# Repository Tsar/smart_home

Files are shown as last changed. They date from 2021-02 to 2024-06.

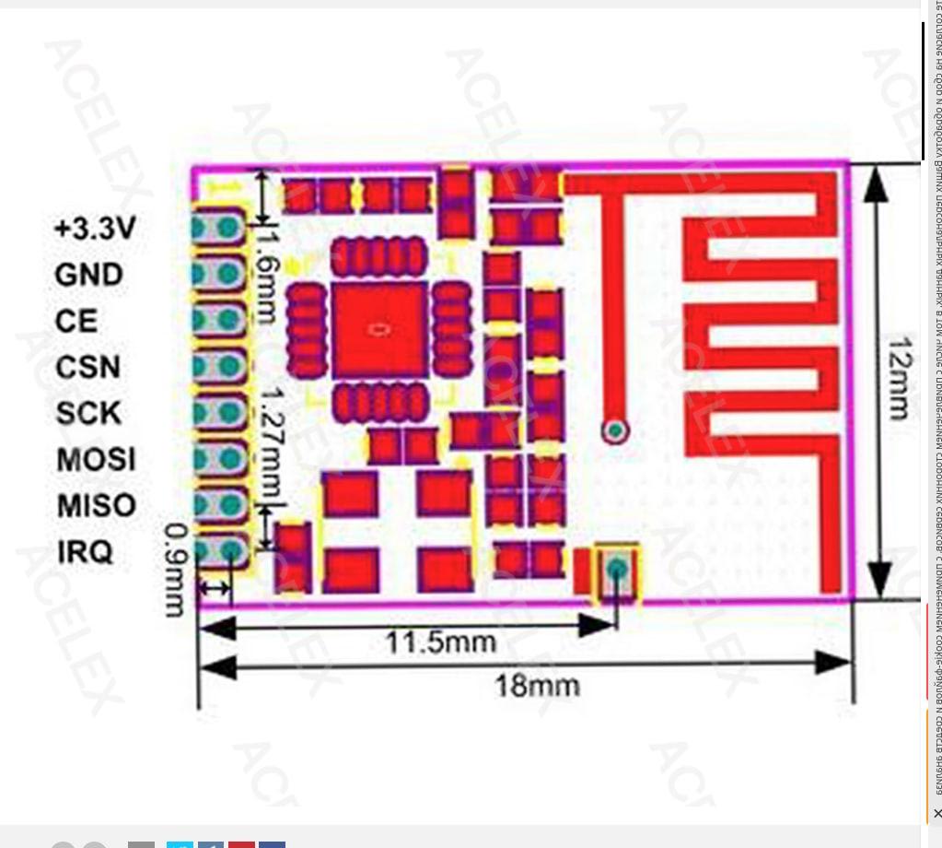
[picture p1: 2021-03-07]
nRF24L01_small_pinout.jpg

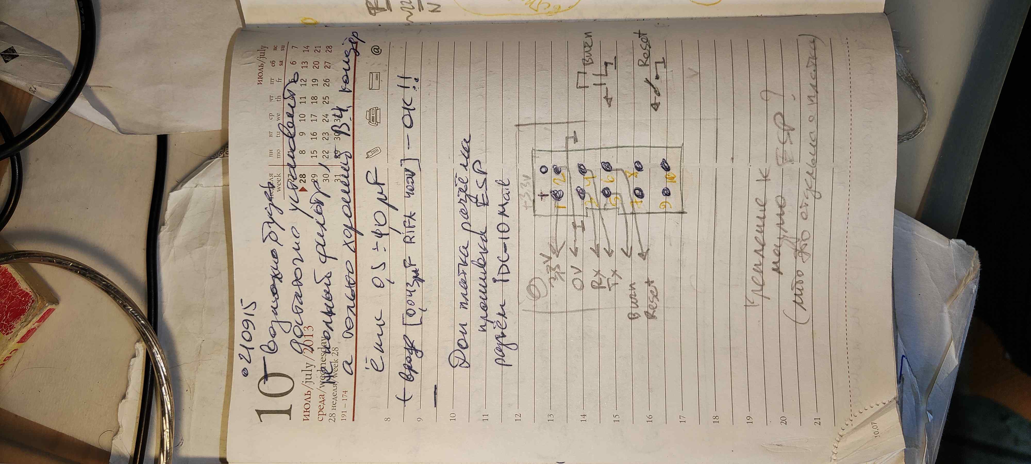
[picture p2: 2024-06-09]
Sprint_Layout_and_other_engineering_stuff/Smart_Home_Foto_Screenshots_Specs/КОнденс фильтра 43нФ 400В Rifa.jpg

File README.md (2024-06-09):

# Smart Home

## Key features

* Smooth light adjustment.
* Turning outlets on/off.
* Control via an Android app from anywhere in the world (with an external IP).
* Voice control via Yandex Alice or a smart speaker with Alice.

## Main project contents by folders

* **App** - Android application.
* **ESP8266_Firmware** - firmware for ESP8266.
* **Sprint_Layout_and_other_engineering_stuff** - contains schematics and other hardware information.
* **Voice_Integration** - script for processing requests from Alice and redirecting them to Smart Home devices.

## Successful usage

The project has been tested over a long period in two apartments. It is still in use in one of them to this day.

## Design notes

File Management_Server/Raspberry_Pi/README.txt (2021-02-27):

Actions to prepare and launch Smart Home Server:

1. sudo apt install make g++ git

2. ./install.sh

3. Choose to install only "RF24 core library"

Next stage is installing RF24 for Python (full doc here: https://nrf24.github.io/RF24/Python.html):

4. sudo apt install python3-dev libboost-python-dev python3-setuptools python3-rpi.gpio

5. sudo ln -s /usr/lib/arm-linux-gnueabihf/libboost_python38.so.1.71.0 /usr/lib/arm-linux-gnueabihf/libboost_python3.so

6. cd rf24libs/RF24/pyRF24/

7. python3 setup.py build

8. sudo python3 setup.py install

9. Change dir to script location

10. Create file "smart_home_password.txt" with password for HTTP access

11. sudo ./smart_home_server.py

Tsar. 27.02.2021

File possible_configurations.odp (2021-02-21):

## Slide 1

HTTP via Internet

Configuration 1

Android App

Ethernet

Raspberry Pi
Management Server

NRF

NRF

STM32
GPIO Switcher

NRF

STM32
GPIO Switcher

NRF

STM32
GPIO Switcher

…………………

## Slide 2

Bluetooth

Configuration 2

Android App

Bluetooth-USART

STM32
Management Server

NRF

NRF

STM32
GPIO Switcher

NRF

STM32
GPIO Switcher

NRF

STM32
GPIO Switcher

…………………

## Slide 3

HTTP via Internet

Configuration 3

Android App

Computer

USB-USART

STM32
Management Server

NRF

NRF

STM32
GPIO Switcher

NRF

STM32
GPIO Switcher

NRF

STM32
GPIO Switcher

…………………

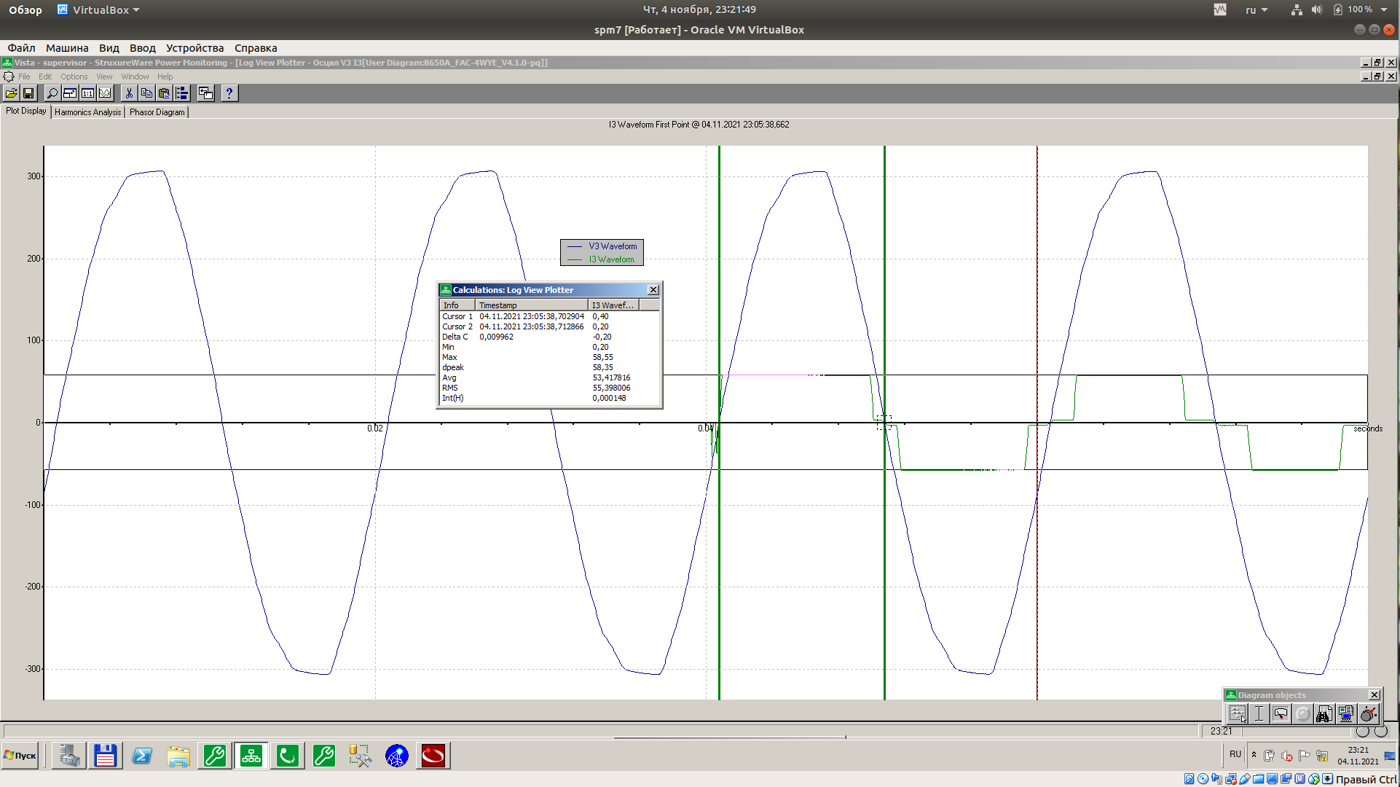
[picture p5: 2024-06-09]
Sprint_Layout_and_other_engineering_stuff/Smart_Home_Foto_Screenshots_Specs/Пик ток 58мА димм лампа Навиг7 W.png

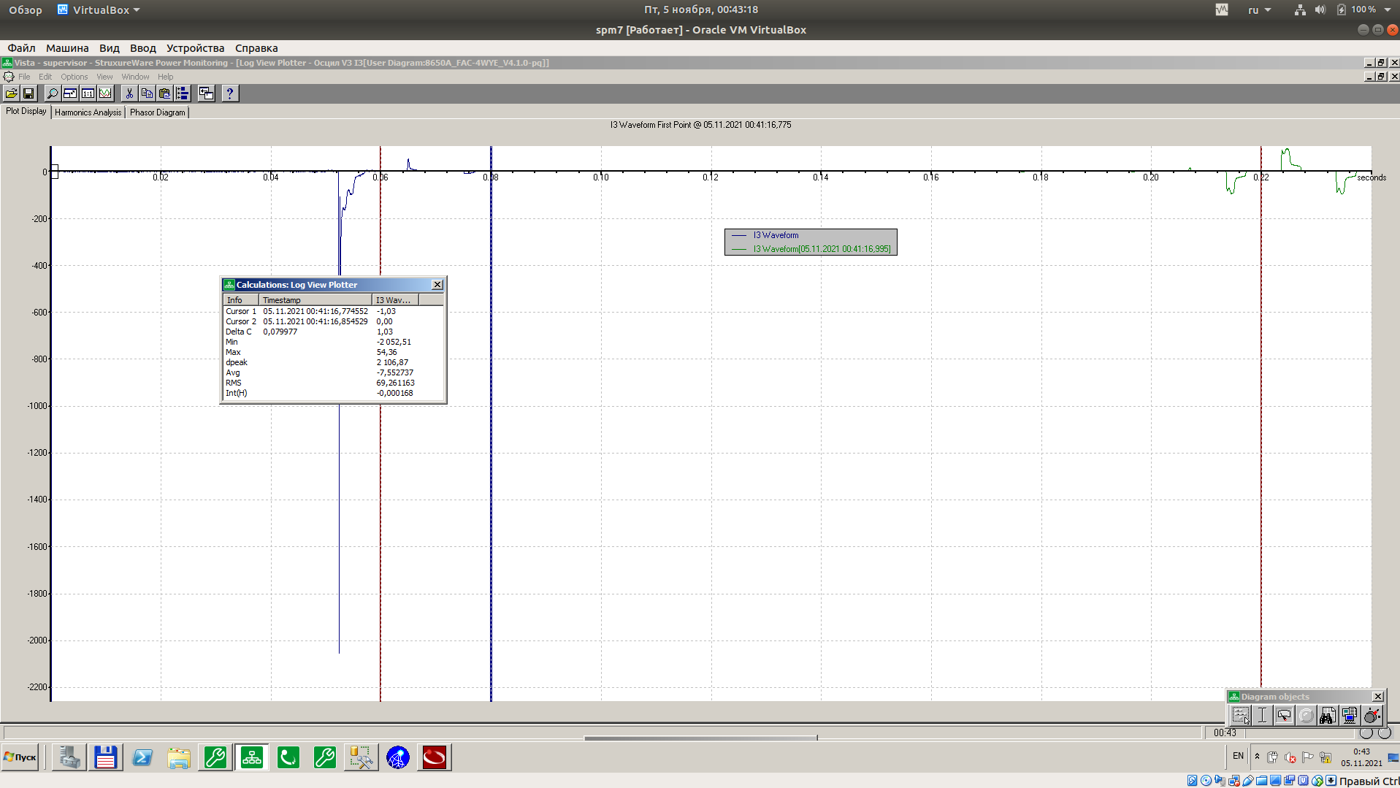
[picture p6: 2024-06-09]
Sprint_Layout_and_other_engineering_stuff/Smart_Home_Foto_Screenshots_Specs/Пик ток 2 А Не димм лампа Volpe 7 W.png

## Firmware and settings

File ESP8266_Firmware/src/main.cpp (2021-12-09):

#include <ESP8266WiFi.h>
#include <ESP8266WiFiGratuitous.h>
#include <ESP8266WebServer.h>
#include <ESP8266HTTPUpdateServer.h>
#include <WiFiUdp.h>
#include <lwip/igmp.h>

#include "configuration.hpp"

#define SIGN(val) (val > 0 ? 1 : (val < 0 ? -1 : 0))
#define MIN(val1, val2) ((val1) < (val2) ? (val1) : (val2))

#define HTTP_SERVER_PORT 80

#define FIRMWARE_VERSION 6  // used as uint16_t, increase when making new firmware version

#define UPDATER_USERNAME "admin"

#define DIMMER_PREFIX   "dim"
#define SWITCHER_PREFIX "sw"

#define INPUT_PIN 14  // for 50 Hz meander

volatile uint32_t inputFallTimeMs = 0;
volatile uint32_t inputFallsCount = 0;

const uint8_t DIMMER_PINS[DIMMERS_COUNT] = {4, 5, 12};
const uint8_t SWITCHER_PINS[SWITCHERS_COUNT] = {13, 15};

#define DIMMER_MAX_VALUE 1000

volatile int32_t dimmerValues[DIMMERS_COUNT] = {};  // 0 - диммер выключен, 1 - минимальная яркость, 1000 - максимальная яркость
volatile int32_t targetDimmerValues[DIMMERS_COUNT] = {};

const volatile smart_home::DimmerSettings* dimmersSettings;

struct Event {
  uint32_t ticks;  // число тиков таймера, начиная от input fall
  uint8_t pin;
  uint8_t value;
};

#define DIMMER_EVENTS_COUNT 4  // число событий для одного выхода диммера

// настройки событий
const uint32_t EVENT_ADDITIONAL_OFFSETS[DIMMER_EVENTS_COUNT] = {0, 500, 50000, 50500};
const uint8_t  EVENT_VALUES            [DIMMER_EVENTS_COUNT] = {HIGH, LOW, HIGH, LOW};

#define MAX_EVENTS_COUNT (DIMMERS_COUNT * DIMMER_EVENTS_COUNT)

volatile Event eventsQueue[MAX_EVENTS_COUNT];
volatile uint8_t eventsQueueSize = 0;
volatile uint8_t nextEventId = 0;

ESP8266WebServer server(HTTP_SERVER_PORT);
ESP8266HTTPUpdateServer updateServer;  // for updating firmware over wi-fi
smart_home::Configuration homeCfg;

std::vector<char> binInfoStorage;

enum class WiFiSetupState {
  NONE,
  IN_PROGRESS,
  FAIL,
  SUCCESS
};

WiFiSetupState wifiSetupState = WiFiSetupState::NONE;
int8_t wifiConnectResult = 0;
bool isAccessPointEnabled = false;

// Для обнаружения
const String UDP_SCAN_REQUEST = "SMART_HOME_SCAN";  // should fit udpInputBuffer
const IPAddress UDP_MULTICAST_IP(227, 16, 119, 203);
#define UDP_MULTICAST_PORT 25061
#define UDP_RESPONSE_PORT  25062

WiFiUDP udp;
char udpInputBuffer[32];
uint32_t udpScanCounter = 0;

#define REJOIN_MULTICAST_GROUP_INTERVAL 120000  // 2 minutes
Ticker rejoinMulticastGroupTicker;

// Кодовая последовательность продолжительности включений контроллера для сброса настроек wi-fi, допустимо отклонение на 20%
const std::vector<uint32_t> WIFI_RESET_SEQUENCE = {20000, 2000, 10000};
Ticker wifiResetSequenceDetectorTicker;

// Плавное изменение яркости
ICACHE_RAM_ATTR void smoothLightnessChange() {
  for (uint8_t i = 0; i < DIMMERS_COUNT; ++i) {
    const int32_t delta = targetDimmerValues[i] - dimmerValues[i];
    if (delta != 0) {
      const int32_t valueChangeStep = dimmersSettings[i].valueChangeStep;
      dimmerValues[i] += std::abs(delta) > valueChangeStep ? SIGN(delta) * valueChangeStep : delta;
    }
  }
}

#define COSINE_FORMULA  // если закомментировать, то будет линейная интерполяция

#ifdef COSINE_FORMULA
// Не удаётся использовать обычный cos, прошивка начинает крешиться (видимо, потому что он не в RAM)
// Источник этой реализации: https://stackoverflow.com/a/28050328
ICACHE_RAM_ATTR double fastCos(double x) {
    constexpr double tp = 1. / (2. * PI);
    x *= tp;
    x -= 0.25 + static_cast<int>(x + 0.25);  // using static_cast instead of floor, because in our case following is always true: x + 0.25 > 0
    x *= 16. * (std::abs(x) - 0.5);
    x += 0.225 * x * (std::abs(x) - 1.);
    return x;
}
#endif

// Переводит значение со слайдера в отступ импульса в микросекундах, см. dimmer_micros_adjustment.png
ICACHE_RAM_ATTR uint32_t dimmerValueToMicros(int32_t value, uint8_t dimmerId) {
  const int32_t minLM = dimmersSettings[dimmerId].minLightnessMicros;  // дефолт = 8300
  const int32_t maxLM = dimmersSettings[dimmerId].maxLightnessMicros;  // дефолт = 4000
#ifdef COSINE_FORMULA
  return fastCos(PI * (value - 1) / 2 / (DIMMER_MAX_VALUE - 1)) * (minLM - maxLM) + maxLM + 0.5;
#else
  return static_cast<double>(value - 1) * (maxLM - minLM) / (DIMMER_MAX_VALUE - 1) + minLM;
#endif
}

// Формируем новую очередь событий, начнутся со следующего input fall
ICACHE_RAM_ATTR void createEventsQueue() {
  uint8_t ev = 0;
  for (uint8_t i = 0; i < DIMMERS_COUNT; ++i) {
    if (dimmerValues[i] <= 0) {
      // для подстраховки: пин по идее и без этого должен стоять в LOW
      digitalWrite(DIMMER_PINS[i], LOW);
    } else {
      // добавляем 4 события для диммера в очередь
      const uint32_t offsetTicks = 5 * dimmerValueToMicros(dimmerValues[i], i);
      for (uint8_t j = 0; j < DIMMER_EVENTS_COUNT; ++j) {
        eventsQueue[ev].pin = DIMMER_PINS[i];
        eventsQueue[ev].ticks = offsetTicks + EVENT_ADDITIONAL_OFFSETS[j];
        eventsQueue[ev].value = EVENT_VALUES[j];
        ++ev;
      }
    }
  }
  eventsQueueSize = ev;

  // bubble sort is good enough for 12 or less elements
  for (uint8_t i = 0; i < eventsQueueSize - 1; ++i) {
    for (uint8_t j = 0; j < eventsQueueSize - i - 1; ++j) {
      if (eventsQueue[j].ticks > eventsQueue[j + 1].ticks) {
        std::swap(eventsQueue[j].ticks, eventsQueue[j + 1].ticks);
        std::swap(eventsQueue[j].pin, eventsQueue[j + 1].pin);
        std::swap(eventsQueue[j].value, eventsQueue[j + 1].value);
      }
    }
  }
}

ICACHE_RAM_ATTR void onInputFall() {
  // защита от многократных срабатываний на одном FALLING
  // и от срабатываний на RISING, которые тоже иногда случались
  const uint32_t now = millis();
  if (now - inputFallTimeMs < 15) return;
  inputFallTimeMs = now;
  ++inputFallsCount;

  nextEventId = 0;
  if (eventsQueueSize > 0) {
    timer1_write(eventsQueue[0].ticks);
  } else {
    smoothLightnessChange();
    createEventsQueue();
  }
}

ICACHE_RAM_ATTR void onTimerISR() {
  if (nextEventId >= eventsQueueSize) return;

  // выполнить event
  const auto& event = eventsQueue[nextEventId++];
  digitalWrite(event.pin, event.value);

  // выполнить все следующие event'ы с такой же меткой времени
  while (nextEventId < eventsQueueSize && eventsQueue[nextEventId].ticks == event.ticks) {
    const auto& nextEvent = eventsQueue[nextEventId];
    digitalWrite(nextEvent.pin, nextEvent.value);
    ++nextEventId;
  }

  if (nextEventId < eventsQueueSize) {
    const uint32_t ticksTillNextEvent = eventsQueue[nextEventId].ticks - event.ticks;  // в случае корректной работы всегда будет >= 5
    timer1_write(ticksTillNextEvent >= 5 ? ticksTillNextEvent : 5);                    // но подстрахуемся
  } else {
    // после выполнения всех event'ов
    smoothLightnessChange();
    createEventsQueue();
  }
}

void initCfgDimmerValuesAfterBoot() {
  const uint16_t dimmerValueAfterBoot = homeCfg.getDimmerValueAfterBoot();
  if (dimmerValueAfterBoot != 0xFFFF) {
    for (uint8_t i = 0; i < DIMMERS_COUNT; ++i) {
      homeCfg.setDimmerValue(i, MIN(dimmerValueAfterBoot, DIMMER_MAX_VALUE));
    }
  }
}

void fillDimmerValues() {
  for (uint8_t i = 0; i < DIMMERS_COUNT; ++i) {
    targetDimmerValues[i] = homeCfg.getDimmerValue(i);
  }
}

void initCfgSwitcherValuesAfterBoot() {
  const uint8_t switcherValueAfterBoot = homeCfg.getSwitcherValueAfterBoot();
  if (switcherValueAfterBoot != 0xFF) {
    for (uint8_t i = 0; i < SWITCHERS_COUNT; ++i) {
      homeCfg.setSwitcherValue(i, switcherValueAfterBoot > 0);
    }
  }
}

void applySwitcherValues() {
  for (uint8_t i = 0; i < SWITCHERS_COUNT; ++i) {
    digitalWrite(SWITCHER_PINS[i], homeCfg.getSwitcherValue(i) != homeCfg.isSwitcherInverted(i) ? HIGH : LOW);
  }
}

void fastBlinkForever() {
  while (true) {
    digitalWrite(LED_BUILTIN, LOW);
    delay(30);
    digitalWrite(LED_BUILTIN, HIGH);
    delay(30);
  }
}

// Same as WiFi.disconnect(true), but without touching config
void disconnectWiFi() {
    if (WiFi.getMode() & WIFI_STA) {
      wifi_station_disconnect();
    }
    WiFi.enableSTA(false);
}

void rejoinMulticastGroup() {
  const auto& ip = WiFi.localIP();
  Serial.printf("IGMP leave group %s\n", igmp_leavegroup(ip, UDP_MULTICAST_IP) == ERR_OK ? "OK" : "failed");
  Serial.printf("IGMP join group %s\n", igmp_joingroup(ip, UDP_MULTICAST_IP) == ERR_OK ? "OK" : "failed");
}

void enableAccessPoint() {
  if (isAccessPointEnabled) return;

  uint8_t mac[WL_MAC_ADDR_LENGTH];
  WiFi.macAddress(mac);
  char softAPName[32] = {};
  sprintf(softAPName, "SmartHomeDevice_%02X%02X%02X", mac[3], mac[4], mac[5]);

  Serial.printf("Enabling access point '%s' ... ", softAPName);
  const bool result = WiFi.softAP(softAPName, "setup12345");
  if (!result) {
    Serial.println("Failed");
    fastBlinkForever();
    return;
  }

  const String ip = WiFi.softAPIP().toString();
  Serial.printf("Access point enabled, IP: %s\n", ip.c_str());
  digitalWrite(LED_BUILTIN, LOW);
  isAccessPointEnabled = true;
}

bool connectToWiFi(const char* ssid, const char* passphrase, bool connectInfinitely) {
  digitalWrite(LED_BUILTIN, LOW);
  udp.stop();

  Serial.printf("Connecting to wi-fi: SSID '%s', passphrase '%s'\n", ssid, passphrase);
  WiFi.begin(ssid, passphrase);

  wifiConnectResult = WiFi.waitForConnectResult(30000);
  while (wifiConnectResult != WL_CONNECTED) {
    if (!connectInfinitely) {
      Serial.printf("Failed to connect, status: %d\n", wifiConnectResult);
      return false;
    }
    Serial.printf("Not yet connected, status: %d\n", wifiConnectResult);
    delay(1000);  // making delay for part of wait, because sometimes waitForConnectResult exits immediately
    wifiConnectResult = WiFi.waitForConnectResult(9000);
  }

  const auto& ip = WiFi.localIP();
  Serial.printf("Connected, IP: %s\n", ip.toString().c_str());
  digitalWrite(LED_BUILTIN, HIGH);

  // This should partly help for quick responses, details: https://github.com/esp8266/Arduino/issues/6886
  experimental::ESP8266WiFiGratuitous::stationKeepAliveSetIntervalMs();

  const bool listeningMulticast = udp.beginMulticast(ip, UDP_MULTICAST_IP, UDP_MULTICAST_PORT);
  if (listeningMulticast) {
    Serial.printf("Started listening UDP multicast on %s:%d\n", UDP_MULTICAST_IP.toString().c_str(), UDP_MULTICAST_PORT);
    rejoinMulticastGroupTicker.detach();
    rejoinMulticastGroupTicker.attach_ms_scheduled(REJOIN_MULTICAST_GROUP_INTERVAL, rejoinMulticastGroup);
  } else {
    Serial.println("Failed to start listening UDP multicast");
  }

  return true;
}

bool checkPassword() {
  if (server.hasHeader("Password") && server.header("Password") == homeCfg.getPassword()) {
    return true;
  }
  server.send(403, "text/plain", "Forbidden");
  Serial.printf("Sent 403 for %s\n", server.uri().c_str());
  return false;
}

void sendBadRequest() {
  server.send(400, "text/plain", "Bad Request");
  Serial.printf("Sent 400 for %s\n", server.uri().c_str());
}

// Create JSON (inefficient function, only for manual debugging)
String generateInfoJson(bool minimal) {
  String result = "{\n  \"mac\": \"" + WiFi.macAddress()
              + "\",\n  \"name\": \"" + homeCfg.getName()
              + "\",\n  \"firmware_version\": " + String(FIRMWARE_VERSION);
  if (!minimal) {
    result += ",\n  \"values\": {\n    \"";
    for (uint8_t i = 0; i < DIMMERS_COUNT; ++i) {
      result += DIMMER_PREFIX + String(i) + "\": " + String(homeCfg.getDimmerValue(i)) + ",\n    \"";
    }
    for (uint8_t i = 0; i < SWITCHERS_COUNT; ++i) {
      result += SWITCHER_PREFIX + String(i) + "\": " + (homeCfg.getSwitcherValue(i) ? "1" : "0") + (i + 1 == SWITCHERS_COUNT ? "" : ",\n    \"");
    }
    result += "\n  },\n  \"micros\": {\n    \"";
    for (uint8_t i = 0; i < DIMMERS_COUNT; ++i) {
      const uint16_t value = homeCfg.getDimmerValue(i);
      result += DIMMER_PREFIX + String(i) + "\": " + String(value > 0 ? dimmerValueToMicros(value, i) : -1) + (i + 1 == DIMMERS_COUNT ? "" : ",\n    \"");
    }
    result += "\n  },\n  \"dimmers_settings\": {\n    \"";
    for (uint8_t i = 0; i < DIMMERS_COUNT; ++i) {
      result += DIMMER_PREFIX + String(i) + "\": {\n      \"value_change_step\": " + String(dimmersSettings[i].valueChangeStep)
                                              + ",\n      \"min_lightness_micros\": " + String(dimmersSettings[i].minLightnessMicros)
                                              + ",\n      \"max_lightness_micros\": " + String(dimmersSettings[i].maxLightnessMicros)
                                              + "\n    }" + (i + 1 == DIMMERS_COUNT ? "" : ",\n    \"");
    }
    result += "\n  },\n  \"dimmer_value_after_boot\": " + String(homeCfg.getDimmerValueAfterBoot()) + ",\n  \"switchers_inverted\": {\n    \"";
    for (uint8_t i = 0; i < SWITCHERS_COUNT; ++i) {
      result += SWITCHER_PREFIX + String(i) + "\": " + (homeCfg.isSwitcherInverted(i) ? "1" : "0") + (i + 1 == SWITCHERS_COUNT ? "" : ",\n    \"");
    }
    result += "\n  },\n  \"switcher_value_after_boot\": " + String(homeCfg.getSwitcherValueAfterBoot()) + ",\n  \"additional_blob\": \"";
    const String& additionalBlob = homeCfg.getAdditionalBlob();
    for (unsigned int i = 0; i < additionalBlob.length(); ++i) {
      result += String(additionalBlob[i], 16) + (i + 1 == additionalBlob.length() ? "" : " ");
    }
    const auto currentUptime = millis();
    result += "\",\n  \"uptime_ms\": " + String(currentUptime)
            + ",\n  \"input_falls_count\": " + String(inputFallsCount)
            + ",\n  \"average_input_fall_interval_ms\": " + String(static_cast<double>(currentUptime) / inputFallsCount, 5);
  }
  result += "\n}\n";
  return result;
}

class UnalignedBinarySerializer {
public:
  UnalignedBinarySerializer(char* buffer) : buffer_(buffer), pos_(0) {}

  void writeWiFiMacAddress() {
    WiFi.macAddress(reinterpret_cast<uint8_t*>(buffer_ + pos_));
    pos_ += WL_MAC_ADDR_LENGTH;
  }

  void writeUInt8(uint8_t value) {
    buffer_[pos_++] = value;
  }

  void writeUInt16(uint16_t value) {
    memcpy(buffer_ + pos_, &value, 2);
    pos_ += 2;
  }

  void writeString(String value) {
    writeUInt16(value.length());
    memcpy(buffer_ + pos_, value.c_str(), value.length());
    pos_ += value.length();
  }

  size_t getWrittenSize() const {
    return pos_;
  }

private:
  char* buffer_;
  size_t pos_;
};

// Fill binInfoStorage
void generateInfoBinary(uint8_t version) {
  const bool v3 = version >= 3;  // request is for v3 or more
  const bool v4 = version >= 4;  // request is for v4 or more

  const String name = homeCfg.getName();
  const String additionalBlob = homeCfg.getAdditionalBlob();

  //                                                      Sizes of:
  const size_t sz = (v3 ? 2 : 0)                            // response format version (appeared from 3+)
                  + (v4 ? 2 : 0)                            // firmware version (appeared from 4+)
                  + WL_MAC_ADDR_LENGTH                      // MAC
                  + 2 + name.length()                       // name length and name
                  + 1                                       // input pin number
                  + 1 + DIMMERS_COUNT * 9 + (v3 ? 2 : 0)    // dimmers info
                  + 1 + SWITCHERS_COUNT * 3 + (v3 ? 1 : 0)  // switchers info
                  + 2 + additionalBlob.length();            // some App's GUI display settings
  binInfoStorage.resize(sz);

  UnalignedBinarySerializer serializer(binInfoStorage.data());
  if (v4) {
    serializer.writeUInt16(0x0004);
    serializer.writeUInt16(FIRMWARE_VERSION);
  } else if (v3) {
    serializer.writeUInt16(0x0003);
  }
  serializer.writeWiFiMacAddress();
  serializer.writeString(name);
  serializer.writeUInt8(INPUT_PIN);

  serializer.writeUInt8(DIMMERS_COUNT);
  for (uint8_t i = 0; i < DIMMERS_COUNT; ++i) {
    serializer.writeUInt8(DIMMER_PINS[i]);
    serializer.writeUInt16(homeCfg.getDimmerValue(i));
    serializer.writeUInt16(dimmersSettings[i].valueChangeStep);
    serializer.writeUInt16(dimmersSettings[i].minLightnessMicros);
    serializer.writeUInt16(dimmersSettings[i].maxLightnessMicros);
  }
  if (v3) {
    serializer.writeUInt16(homeCfg.getDimmerValueAfterBoot());
  }

  serializer.writeUInt8(SWITCHERS_COUNT);
  for (uint8_t i = 0; i < SWITCHERS_COUNT; ++i) {
    serializer.writeUInt8(SWITCHER_PINS[i]);
    serializer.writeUInt8(homeCfg.getSwitcherValue(i));
    serializer.writeUInt8(homeCfg.isSwitcherInverted(i));
  }
  if (v3) {
    serializer.writeUInt8(homeCfg.getSwitcherValueAfterBoot());
  }

  serializer.writeString(additionalBlob);

  if (serializer.getWrittenSize() != sz) {
    Serial.printf("WARNING: Serialized: %d, expected: %d\n", serializer.getWrittenSize(), sz);
  }
}

void handleGetInfo() {
  const auto tsStart = micros64();

  if (!checkPassword()) return;

  if (server.hasArg("binary")) {
    generateInfoBinary(server.hasArg("v") ? server.arg("v").toInt() : 1);
    server.send(200, "application/octet-stream", binInfoStorage.data(), binInfoStorage.size());
  } else {
    server.send(200, "application/json", generateInfoJson(server.hasArg("minimal")));
  }

  const auto tsEnd = micros64();
  Serial.printf("Handled %s, spent %.2lf ms\n", server.uri().c_str(), (tsEnd - tsStart) / 1000.0);
}

void handleSetupWiFi() {
  if (!checkPassword()) return;

  if (!server.hasArg("ssid") || !server.hasArg("passphrase")) {
    sendBadRequest();
    return;
  }

  wifiSetupState = WiFiSetupState::IN_PROGRESS;
  server.send(200, "text/plain", "TRYING_TO_CONNECT");
  Serial.printf("Sent response to %s\n", server.uri().c_str());
  delay(100);  // задержка нужна, чтобы успеть отправить ответ до попытки
  disconnectWiFi();
  wifiSetupState = connectToWiFi(server.arg("ssid").c_str(), server.arg("passphrase").c_str(), false)
                      ? WiFiSetupState::SUCCESS
                      : WiFiSetupState::FAIL;
  // Если пытаться отправить ответ сервера здесь, то клиент получает ошибку:
  // curl скажет "empty reply from server", android скажет "unexpected end of stream on com.android.okhttp.Address"
}

void handleGetSetupWiFiState() {
  if (!checkPassword()) return;

  String result;
  switch (wifiSetupState) {
    case WiFiSetupState::NONE:
      result = "NONE";
      break;
    case WiFiSetupState::IN_PROGRESS:
      result = "IN_PROGRESS";
      break;
    case WiFiSetupState::FAIL:
      result = "FAIL:" + String(wifiConnectResult);
      break;
    case WiFiSetupState::SUCCESS:
      result = "SUCCESS:" + WiFi.localIP().toString();
      break;
  }
  server.send(200, "text/plain", result);
  Serial.printf("Handled %s (response: %s)\n", server.uri().c_str(), result.c_str());
}

void handleResetWiFi() {
  if (!checkPassword()) return;

  server.send(200, "text/plain", "OK");
  delay(100);
  Serial.println("Reset wi-fi credentials by request");
  WiFi.disconnect(true);
  enableAccessPoint();
}

void handleTurnOffAccessPoint() {
  if (!checkPassword()) return;

  server.send(200, "text/plain", "OK");
  delay(100);
  WiFi.softAPdisconnect(true);
  isAccessPointEnabled = false;
  Serial.println("Access point disabled by request");
}

void handleSetValues() {
  const auto tsStart = micros64();

  if (!checkPassword()) return;

  bool dimmersChanged = false;
  for (uint8_t i = 0; i < DIMMERS_COUNT; ++i) {
    const String argName = DIMMER_PREFIX + String(i);
    if (server.hasArg(argName)) {
      const int32_t value = server.arg(argName).toInt();
      if (value < 0 || value > DIMMER_MAX_VALUE) {
        sendBadRequest();
        return;
      }
      if (value != homeCfg.getDimmerValue(i)) {
        homeCfg.setDimmerValue(i, value);
        dimmersChanged = true;
      }
    }
  }

  bool switchersChanged = false;
  for (uint8_t i = 0; i < SWITCHERS_COUNT; ++i) {
    const String argName = SWITCHER_PREFIX + String(i);
    if (server.hasArg(argName)) {
      const bool value = server.arg(argName).toInt();
      if (value != homeCfg.getSwitcherValue(i)) {
        homeCfg.setSwitcherValue(i, value);
        switchersChanged = true;
      }
    }
  }

  bool accepted = false;
  if (dimmersChanged || switchersChanged) {
    if (dimmersChanged) {
      fillDimmerValues();
    }
    if (switchersChanged) {
      applySwitcherValues();
    }
    server.send(200, "text/plain", "ACCEPTED\n");

    // saving only if saved values will be needed after boot
    if ((dimmersChanged && homeCfg.getDimmerValueAfterBoot() == 0xFFFF) ||
        (switchersChanged && homeCfg.getSwitcherValueAfterBoot() == 0xFF)) {
      homeCfg.asyncSave();
    }

    accepted = true;
  } else {
    server.send(200, "text/plain", "NOTHING_CHANGED\n");
  }

  const auto tsEnd = micros64();
  Serial.printf(
    "Handled %s, spent %.2lf ms, %s\n",
    server.uri().c_str(),
    (tsEnd - tsStart) / 1000.0,
    accepted ? "accepted new values" : "nothing was changed"
  );
}
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
void loop() {
  server.handleClient();
  udpHandlePacket();
}

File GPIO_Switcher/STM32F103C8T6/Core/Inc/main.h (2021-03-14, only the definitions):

#define OnboardLED_Pin GPIO_PIN_13
#define OnboardLED_GPIO_Port GPIOC
#define IRQ_Pin GPIO_PIN_2
#define IRQ_GPIO_Port GPIOA
#define CE_Pin GPIO_PIN_3
#define CE_GPIO_Port GPIOA
#define CSN_Pin GPIO_PIN_4
#define CSN_GPIO_Port GPIOA
#define OUT1_Pin GPIO_PIN_1
#define OUT1_GPIO_Port GPIOB
#define OUT2_Pin GPIO_PIN_2
#define OUT2_GPIO_Port GPIOB
#define OUT3_Pin GPIO_PIN_3
#define OUT3_GPIO_Port GPIOB
#define OUT4_Pin GPIO_PIN_4
#define OUT4_GPIO_Port GPIOB
#define OUT5_Pin GPIO_PIN_5
#define OUT5_GPIO_Port GPIOB
#define OUT6_Pin GPIO_PIN_6
#define OUT6_GPIO_Port GPIOB
#define DEVICE_UUID 0x00011991

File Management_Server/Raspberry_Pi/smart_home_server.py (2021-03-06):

#!/usr/bin/env python3

# Line for crontab:
#   @reboot cd /home/ubuntu && screen -dmS smart_home_server sudo ./smart_home_server.py

# Command for testing without client:
#   echo  -ne '\xCE\xBF\x01\x02\xFF\xAA' | curl -s -X POST -H 'Password: <password>' --data-binary @- http://<address>:9732/uart_message | hexdump -C

import os.path
import struct
import threading
import json
import time
from concurrent.futures import ThreadPoolExecutor

from RF24 import RF24, RF24_PA_MAX, RF24_1MBPS

from uart_http_server import UARTMessage, BaseUARTMessageHandler, launchServer

class DeviceParams:
    DEVICE_PARAMS_FMT = '<II'  # nameId, uuid
    DEVICE_PARAMS_SZ = struct.calcsize(DEVICE_PARAMS_FMT)

    KEY_NAME_ID = 'nameId'
    KEY_UUID = 'uuid'

    def __init__(self, deviceJsonOrBytes):
        if isinstance(deviceJsonOrBytes, dict):
            self.nameId = deviceJsonOrBytes[self.KEY_NAME_ID]
            self.uuid = deviceJsonOrBytes[self.KEY_UUID]
        elif isinstance(deviceJsonOrBytes, bytes) and len(deviceJsonOrBytes) == self.DEVICE_PARAMS_SZ:
            self.nameId, self.uuid = struct.unpack(self.DEVICE_PARAMS_FMT, deviceJsonOrBytes)
        else:
            raise RuntimeError('Bad type of deviceJsonOrBytes argument')

    def toDict(self):
        return {
            self.KEY_NAME_ID: self.nameId,
            self.KEY_UUID: self.uuid
        }

    def serialize(self):
        return struct.pack(self.DEVICE_PARAMS_FMT, self.nameId, self.uuid)

class NRFMessage:
    HEADER_FMT = '<IBB'  # uuid, command, payloadSize
    HEADER_SZ = struct.calcsize(HEADER_FMT)

    COMMAND_GET_STATE      = 0x01
    COMMAND_RESPONSE_STATE = 0xF1

    def __init__(self, uuid=0, command=0, payload=b''):
        self.uuid = uuid
        self.command = command
        self.payload = payload

    def serialize(self):
        return struct.pack(self.HEADER_FMT, self.uuid, self.command, len(self.payload)) + self.payload

    def parse(self, binary):
        if len(binary) < self.HEADER_SZ:
            return False
        self.uuid, self.command, payloadSize = struct.unpack(self.HEADER_FMT, binary[0:self.HEADER_SZ])
        if self.HEADER_SZ + payloadSize != len(binary):
            return False
        self.payload = binary[self.HEADER_SZ:]
        return True

UARTMessage.COMMAND_PING                 = 0x01
UARTMessage.COMMAND_GET_DEVICES          = 0x02
UARTMessage.COMMAND_SET_DEVICES          = 0x03
UARTMessage.COMMAND_GET_DEVICE_STATES    = 0x04
UARTMessage.COMMAND_UPDATE_DEVICE_STATES = 0x05
UARTMessage.COMMAND_SEND_NRF_MESSAGE     = 0x08

UARTMessage.COMMAND_RESPONSE_PING                    = 0x81
UARTMessage.COMMAND_RESPONSE_GET_DEVICES             = 0x82
UARTMessage.COMMAND_RESPONSE_SET_DEVICES             = 0x83
UARTMessage.COMMAND_RESPONSE_GET_DEVICE_STATES       = 0x84
UARTMessage.COMMAND_RESPONSE_UPDATE_DEVICE_STATES    = 0x85
UARTMessage.COMMAND_RESPONSE_SEND_NRF_MESSAGE        = 0x88
UARTMessage.COMMAND_RESPONSE_SEND_NRF_MESSAGE_FAILED = 0xF8


DEVICES_FILE = 'smart_home_devices.json'

DEVICE_STATE_SIZE = 4
DEVICE_UNAVAILABLE_STATE = struct.pack('<I', 0xFF0000FF)

devices = []       # configuration
devicesLock = threading.Lock()

deviceStates = {}  # kind of a cache
deviceStatesLock = threading.Lock()

radio = RF24(22, 0)

radioExchange = ThreadPoolExecutor(max_workers=1)

def readDevicesConfiguration():
    global devices

    if not os.path.isfile(DEVICES_FILE):
        return

    devices = []
    with open(DEVICES_FILE, 'r') as cfg:
        cfgJson = json.loads(cfg.read())
        for deviceJson in cfgJson['devices']:
            devices.append(DeviceParams(deviceJson))

def saveDevicesConfiguration():
    with open(DEVICES_FILE, 'w') as cfg:
        cfg.write(json.dumps({'devices': [device.toDict() for device in devices]}, indent=2))

def sendNRFMessageInternal(message, writeAttempts, readAttempts):
    global radio

    while writeAttempts > 0:
        radio.write(message.serialize())
        radio.startListening()

        readAttemptsLeft = readAttempts
        while readAttemptsLeft > 0:
            time.sleep(0.05)  # TODO: think about reducing this interval
            hasPayload, pipeId = radio.available_pipe()
            if hasPayload and pipeId == 1:
                response = radio.read(radio.getDynamicPayloadSize())
                rxMessage = NRFMessage()
                if rxMessage.parse(response) and rxMessage.uuid == message.uuid:
                    radio.stopListening()
                    return rxMessage
            readAttemptsLeft -= 1

        radio.stopListening();
        writeAttempts -= 1
    return None

def sendNRFMessage(message, writeAttempts=3, readAttempts=3):
    global radioExchange
    return radioExchange.submit(sendNRFMessageInternal, message, writeAttempts, readAttempts).result()

def updateAllDeviceStates():
    global deviceStates
    global deviceStatesLock

    newDeviceStates = {}
    for device in devices:
        result = sendNRFMessage(NRFMessage(device.uuid, NRFMessage.COMMAND_GET_STATE, b''))
        if result is not None and result.command == NRFMessage.COMMAND_RESPONSE_STATE and len(result.payload) == DEVICE_STATE_SIZE:
            newDeviceStates[device.uuid] = result.payload
        else:
            newDeviceStates[device.uuid] = DEVICE_UNAVAILABLE_STATE
    with deviceStatesLock:
        deviceStates = newDeviceStates

def handleUartPing(message):
    return UARTMessage(
        UARTMessage.COMMAND_RESPONSE_PING,
        b''.join([bytes([byte ^ 0xFF]) for byte in message.payload])
    )

def handleUartGetDevices(afterSet):
    global devicesLock

    with devicesLock:
        return UARTMessage(
            UARTMessage.COMMAND_RESPONSE_SET_DEVICES if afterSet else UARTMessage.COMMAND_RESPONSE_GET_DEVICES,
            b''.join([device.serialize() for device in devices])
        )

def handleUartSetDevices(message):
    global devices
    global devicesLock

    devicesCount = len(message.payload) // DeviceParams.DEVICE_PARAMS_SZ
    with devicesLock:
        devices = []
        for i in range(0, devicesCount * DeviceParams.DEVICE_PARAMS_SZ, DeviceParams.DEVICE_PARAMS_SZ):
            devices.append(DeviceParams(message.payload[i:i + DeviceParams.DEVICE_PARAMS_SZ]))
        saveDevicesConfiguration()

        readDevicesConfiguration()     # read back immediately
        updateAllDeviceStates()        # make our "cache" up to date
    return handleUartGetDevices(True)  # send back for verification

def handleUartGetDeviceStates(update):
    global devicesLock
    global deviceStatesLock

    with devicesLock:
        if update:
            updateAllDeviceStates()
        with deviceStatesLock:
            return UARTMessage(
                UARTMessage.COMMAND_RESPONSE_UPDATE_DEVICE_STATES if update else UARTMessage.COMMAND_RESPONSE_GET_DEVICE_STATES,
                b''.join([deviceStates[device.uuid] for device in devices])
            )

class BadNRFMessageException(Exception):
    pass
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

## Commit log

2021-02-04 Wireless data exchange between Raspberry Pi and STM32F103RCT6 using NRF modules works!
2021-02-04 Add info how to setup RF24 on Raspberry Pi
2021-02-06 Having problems with getting response
    [nrf24l01.c, smart_home_server.py]
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2021-02-21 Created "STM32_common_code". Made symlinks from there
2021-02-22 Started writing STM32 Management Server for configurations 2 and 3 (see possible_configuration.pdf)
2021-02-22 Forgot USART1 global interrupt checkbox
2021-02-22 Now HAL_Delay works inside DMA interrupt
2021-02-22 Soft for Raspberry Pi becomes legacy for sometime
2021-02-22 Fix symlinks and .gitignore
    [nrf24l01.c]
2021-02-22 Added Management Server firmware for STM32F103C8T6, only 2 lines of code to main.c and symlinks
2021-02-22 Seems to work on F103. But poweroff between relaunches required
2021-02-22 Updated GPIO Switcher with new protocol
2021-02-27 Rewrited Management Server for Raspberry Pi completely, now it's fresh
2021-02-28 Started receiving devices list
2021-02-28 More work on App, almost getting device states
2021-03-06 Moved GPIO switcher's main code to common code and created switcher based on STM32F103C8T6
2021-03-06 Comment DEVICE_UUID in client.c not to forget to set it to right value
2021-03-06 Switchs actually blink with LED!
2021-03-06 Added Smart Home App release APK for current version
2021-03-07 Getting device names by HTTP
2021-03-08 Menu button to update device states manually
2021-03-14 Replace 3 of GPIO outputs with PWM
    [client.c, main.h, smart_home_F030.ioc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]
2021-04-20 ESP: Set LED by wi-fi
2021-05-01 Moved current version to 'Old_Project_with_STM32_and_NRF24', because ESP-12F (based on ESP8266) suits better
2021-06-06 INPUT_PULLUP -> INPIT and fixed interrupt usage (why it didn'work the old way - I don't yet understand)
    [main.cpp]
2021-06-22 It was working already, but using volatile in interrupt is more correct
    [main.cpp]
2021-08-01 Trying to use hardware timer for pin 4 (other pins disabled)
2021-08-07 Fix multiple fire onInputFall, it fired even on rising sometimes!
    [main.cpp]
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2021-08-07 Fix, but it did not help (works if I reduce dimmer outputs count to 1)
    [main.cpp]
2021-08-07 Refactoring and added switchers. Dimmers: dim0 (pin 4), dim1 (pin 5), dim2 (pin 12); switchers: sw0 (pin 13), sw1 (pin 15)
2021-08-07 Fix writing to Serial before it is opened
    [main.cpp]
2021-08-14 Add 2 more switchers (pins 9 and 10)
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2021-08-18 App: Screen for choosing wi-fi network to connect the Smart Home device to
2021-08-18 App: Home network settings screen, currently gives exception when trying to connect
2021-08-18 App: Fix exception ESP: Do not enable AP when already enabled
    [main.cpp]
2021-08-18 Now device receives credentials, but we get exception in app
2021-08-18 App still gets 'unexpected end of stream on com.android.okhttp.Address' sometimes (even when device connects to wi-fi successfully)
2021-08-20 Add handler to reset and forget wifi
    [main.cpp]
2021-08-20 Switch on buitin LED when enabling access point
2021-08-21 Fix back button with a crutch
2021-08-21 Parsing MAC and IP addresses from device responses
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2021-08-21 First version of devices list and created APK, because some dimmers and switchers testing possible
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2021-08-23 ESP: Got rid of RESET_CONFIGURATION flag, now only one firmware flash required
    [main.cpp]
2021-08-23 ESP: Avoiding theoretically possible exotics
    [main.cpp]
2021-08-24 ESP: Handling UDP multicast, but currently this feature stops working after few minutes from boot
2021-08-25 Add test script for emulating device's UDP response to UDP multicast
2021-08-25 UDP multicast problem is described here: https://stackoverflow.com/a/60397082/1565832. Debugging how to rejoin multicast group. Following already works: leave, wait 500 ms, join
    [main.cpp]
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2021-08-28 App: New APK. Switchs made larger using scale, but this gives a problem of interacting with them: touch works at other place, than the switch is drawn
2021-08-30 App: Fix switchs
2021-08-30 App: Screen for searching configured devices implemented. ESP: Changed format of UDP response
2021-08-30 Added project for STM32F030F4P6 for generating 50 Hz meander. I use it to check that all the routine, based on interrupts and hardware timer, does not crash the ESP firmware
    [Generate_50Hz_Meander_for_Test.ioc, main.h]
2021-08-30 App: Screen with IP and password of configured device. Adding such device not implemented yet
2021-08-31 App: Adding existing device works (still did not do anything about checkbox static IP)
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2021-09-01 App: Borderless buttons look better for tab headers
2021-09-01 App: Pseudo-tabs on device settings screen became even better
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2021-09-02 App & ESP: Continuing making device settings screen
2021-09-02 App & ESP: Intermediate version of saving device settings with 3 HTTP requests
2021-09-02 App & ESP: Saving device settings with one HTTP query. Checking restrictions. New APK
2021-09-04 ESP: Trying to work on stability. Changed connect logic on boot. Set wifi sleep more to None
    [main.cpp]
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2021-09-07 Fix spaces handling in device emulator
2021-09-10 ESP: Using crutch from https://github.com/esp8266/Arduino/issues/6886 (sending ARP broadcasts every second)
    [main.cpp]
2021-09-13 ESP: Implemented code sequence of device uptimes for resetting wi-fi credentials
    [main.cpp]
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2021-09-14 App: Temporary 'unavailable'-message on adding fresh devices on Androids lower than 10. New release APK
2021-09-15 ESP: Fix wi-fi credentials loss on fast resets
    [main.cpp]
2021-09-17 App: Started using RecyclerView for dimmers and switchers settings
2021-09-18 ESP: Also send input pin number in get_info v2
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2021-09-21 Support binary v2 and additional blob in device emulator
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2021-10-09 App: Support any number of dimmers and switchers
2021-10-09 Device emulator now has 5 dimmers and 2 switchers (instead of standard 3 and 4)
2021-10-18 ESP: Fix bug with inverted pin
    [main.cpp]
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2021-10-28 App: Using RecyclerView for main devices list. New release APK
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2021-11-07 OAuth problems moved to next stage
2021-11-09 ESP: Support specified value for dimmer or switcher after boot instead of always using saved value. Binary proto V3
2021-11-09 Alice: Close pool after use (otherwise "RuntimeError: can't start new thread" occurs)
2021-11-11 Alice: Correctly responding about unavailable device on /devices/query instead of using fake value 0
2021-11-20 ESP: Fix v4 binary /get_info response. Set firmware version to 4 to avoid brain blow
    [main.cpp]
2021-11-21 App: Store firmware version to show info about offline devices correctly
2021-11-21 App: Firmware update button which appears when firmware update is available for device. Does not do anything yet
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2021-11-24 Alice: Fix bug and skip non-existing devices
2021-11-26 ESP: Set dimmers to maximum after configuration reset. New firmware version 5
    [main.cpp]
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2021-12-07 Alice: Exclude all phone_find devices if any device in action list is not phone_find (not to ring phone for commands like "turn on/off everything")
2021-12-08 ESP: Removed usage of pin 9, cause it crashes some ESPs. Printing flash chip info
    [main.cpp]
2021-12-09 ESP: Stopped using pin 10 for safety. Prepared migration for configuration format from 5 to 6 (not to have all devices reset)
    [main.cpp]
2021-12-09 ESP: Removed Serial.println which tries to happen before Serial is open. Updated firmware 6
2021-12-14 Alice: Intermediate stage of new implementation for Android Find
2021-12-17 App: Added firebase cloud messaging support. Currently only writing debug logs when handling
2021-12-17 App: Created app settings screen
    [app_settings.xml]
2021-12-18 Alice: Rising priority for firebase messages. Added notification to avoid de-prioritize
2021-12-19 App: Added ScrollView for app settings screen. Updated gradle to 7.0.4
    [app_settings.xml]
2022-01-01 App: Allow to choose one of two sounds for phone find
    [app_settings.xml]
2024-06-09 Add Sprint Layout and other engineering stuff related to the project
    [019_Drill_file.drl, 019_OUTLINE.gbr, 019_SOLDERMASK_BOTTOM.gbr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]

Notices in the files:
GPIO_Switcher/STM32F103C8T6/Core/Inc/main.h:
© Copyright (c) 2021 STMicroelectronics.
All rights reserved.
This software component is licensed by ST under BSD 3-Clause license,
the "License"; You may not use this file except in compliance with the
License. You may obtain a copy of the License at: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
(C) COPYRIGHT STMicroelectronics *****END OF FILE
